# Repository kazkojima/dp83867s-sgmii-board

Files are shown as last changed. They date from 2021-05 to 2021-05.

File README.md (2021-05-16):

# KiCAD files of a SGMII PHY board with TI DP83867S

KiCAD files of a simple SGMII PHY

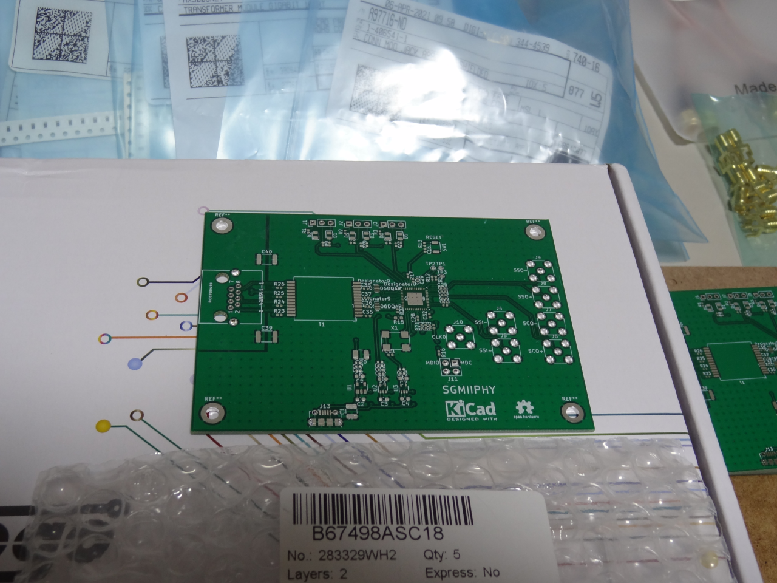
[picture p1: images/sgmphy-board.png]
print board


It works with an ECP5 evaluation board LFE5UM5G-85F-EVN running [LiteX](https://github.com/enjoy-digital/litex).

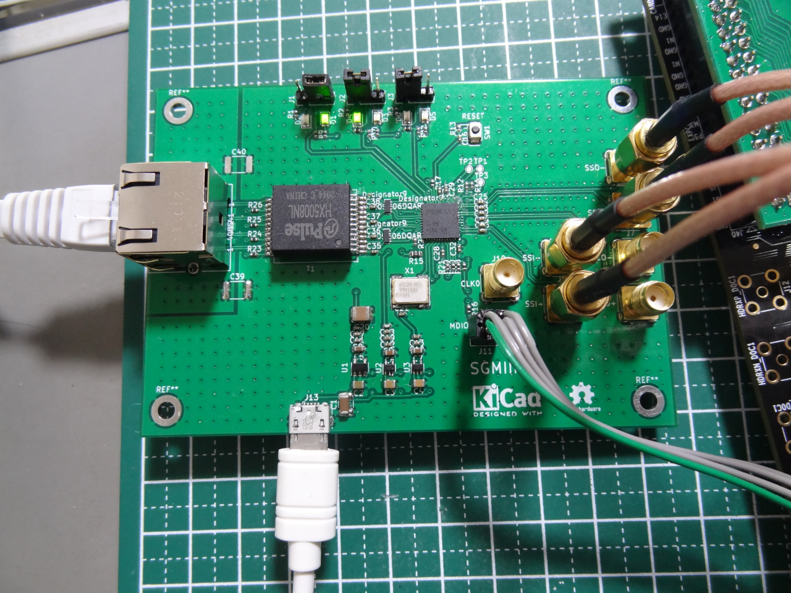
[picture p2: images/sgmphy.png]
With LEF5UM5G-85G


## Problems

* 1.0V LDO will be too hot when supplying 5V. It should be bigger package which has lower junction thermal resistance. 3.3V supply will be OK.

* SMA connectors were a bit too close to each other.

* REFCLK LDVS and CLKOUT outputs could be optional because almost MACs has their own CDR.

* Datasheet says "at minimum a 4-layer PCB should be used. However a 6-layer board is recommended." This 2-layer PCB violates it :-)

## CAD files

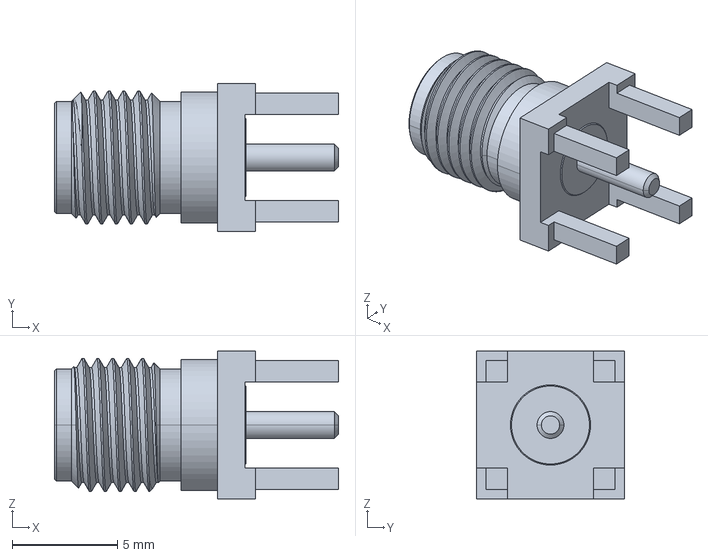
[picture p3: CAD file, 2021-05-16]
anphenole-132134.stp
13.5 x 7.00 x 7.00 mm

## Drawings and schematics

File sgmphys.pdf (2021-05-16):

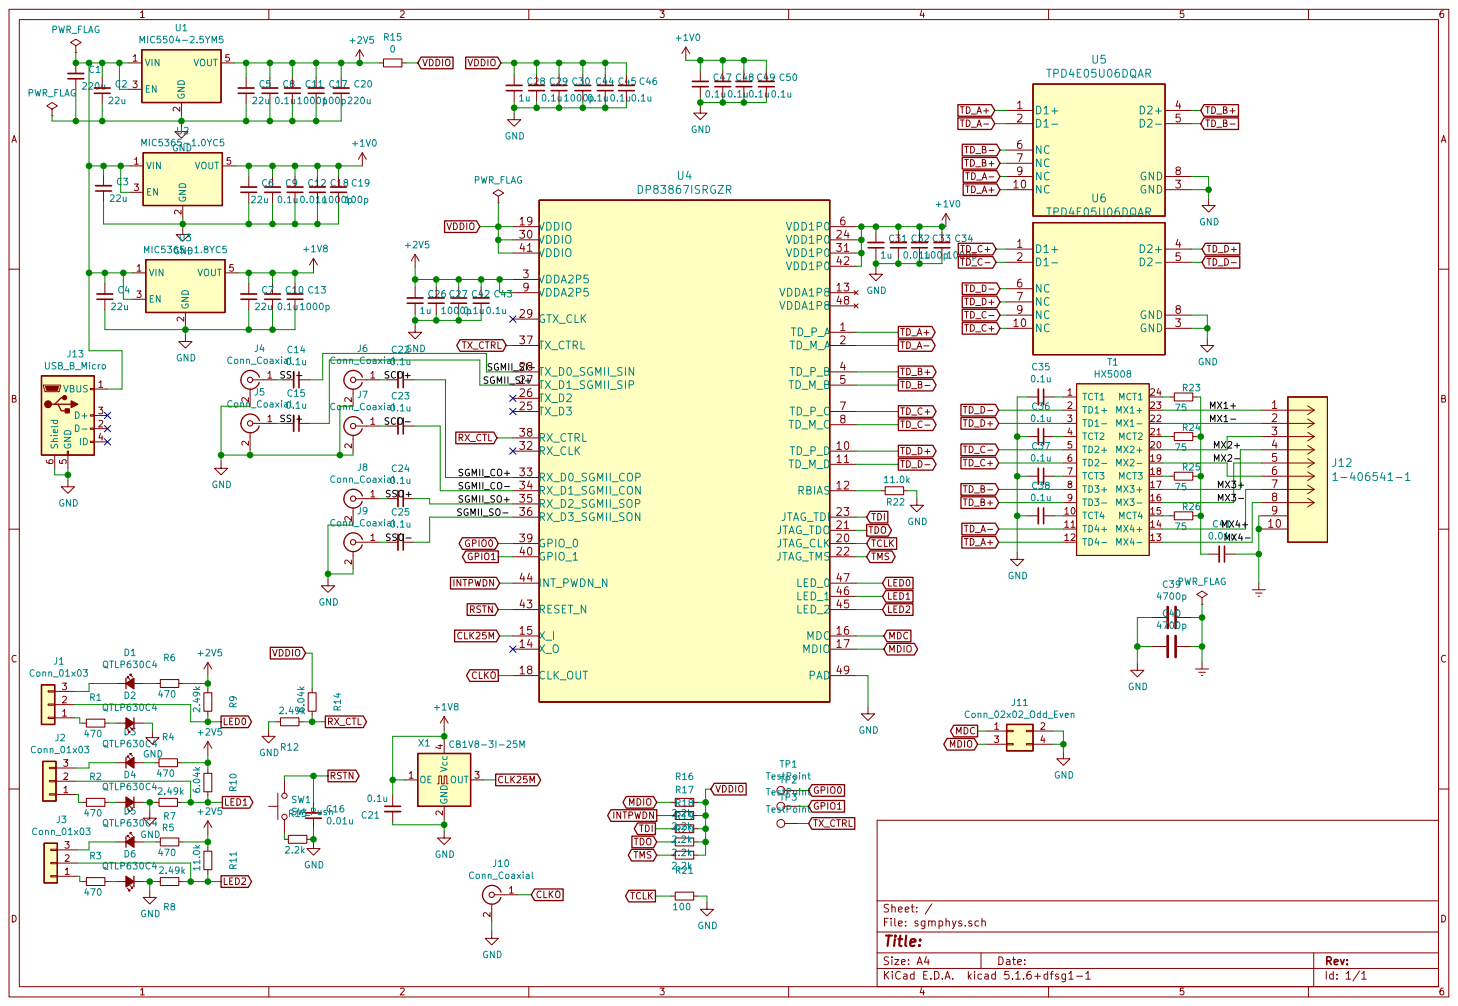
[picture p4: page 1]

File: sgmphys.sch Sheet: /
Id: 1/1 Title:

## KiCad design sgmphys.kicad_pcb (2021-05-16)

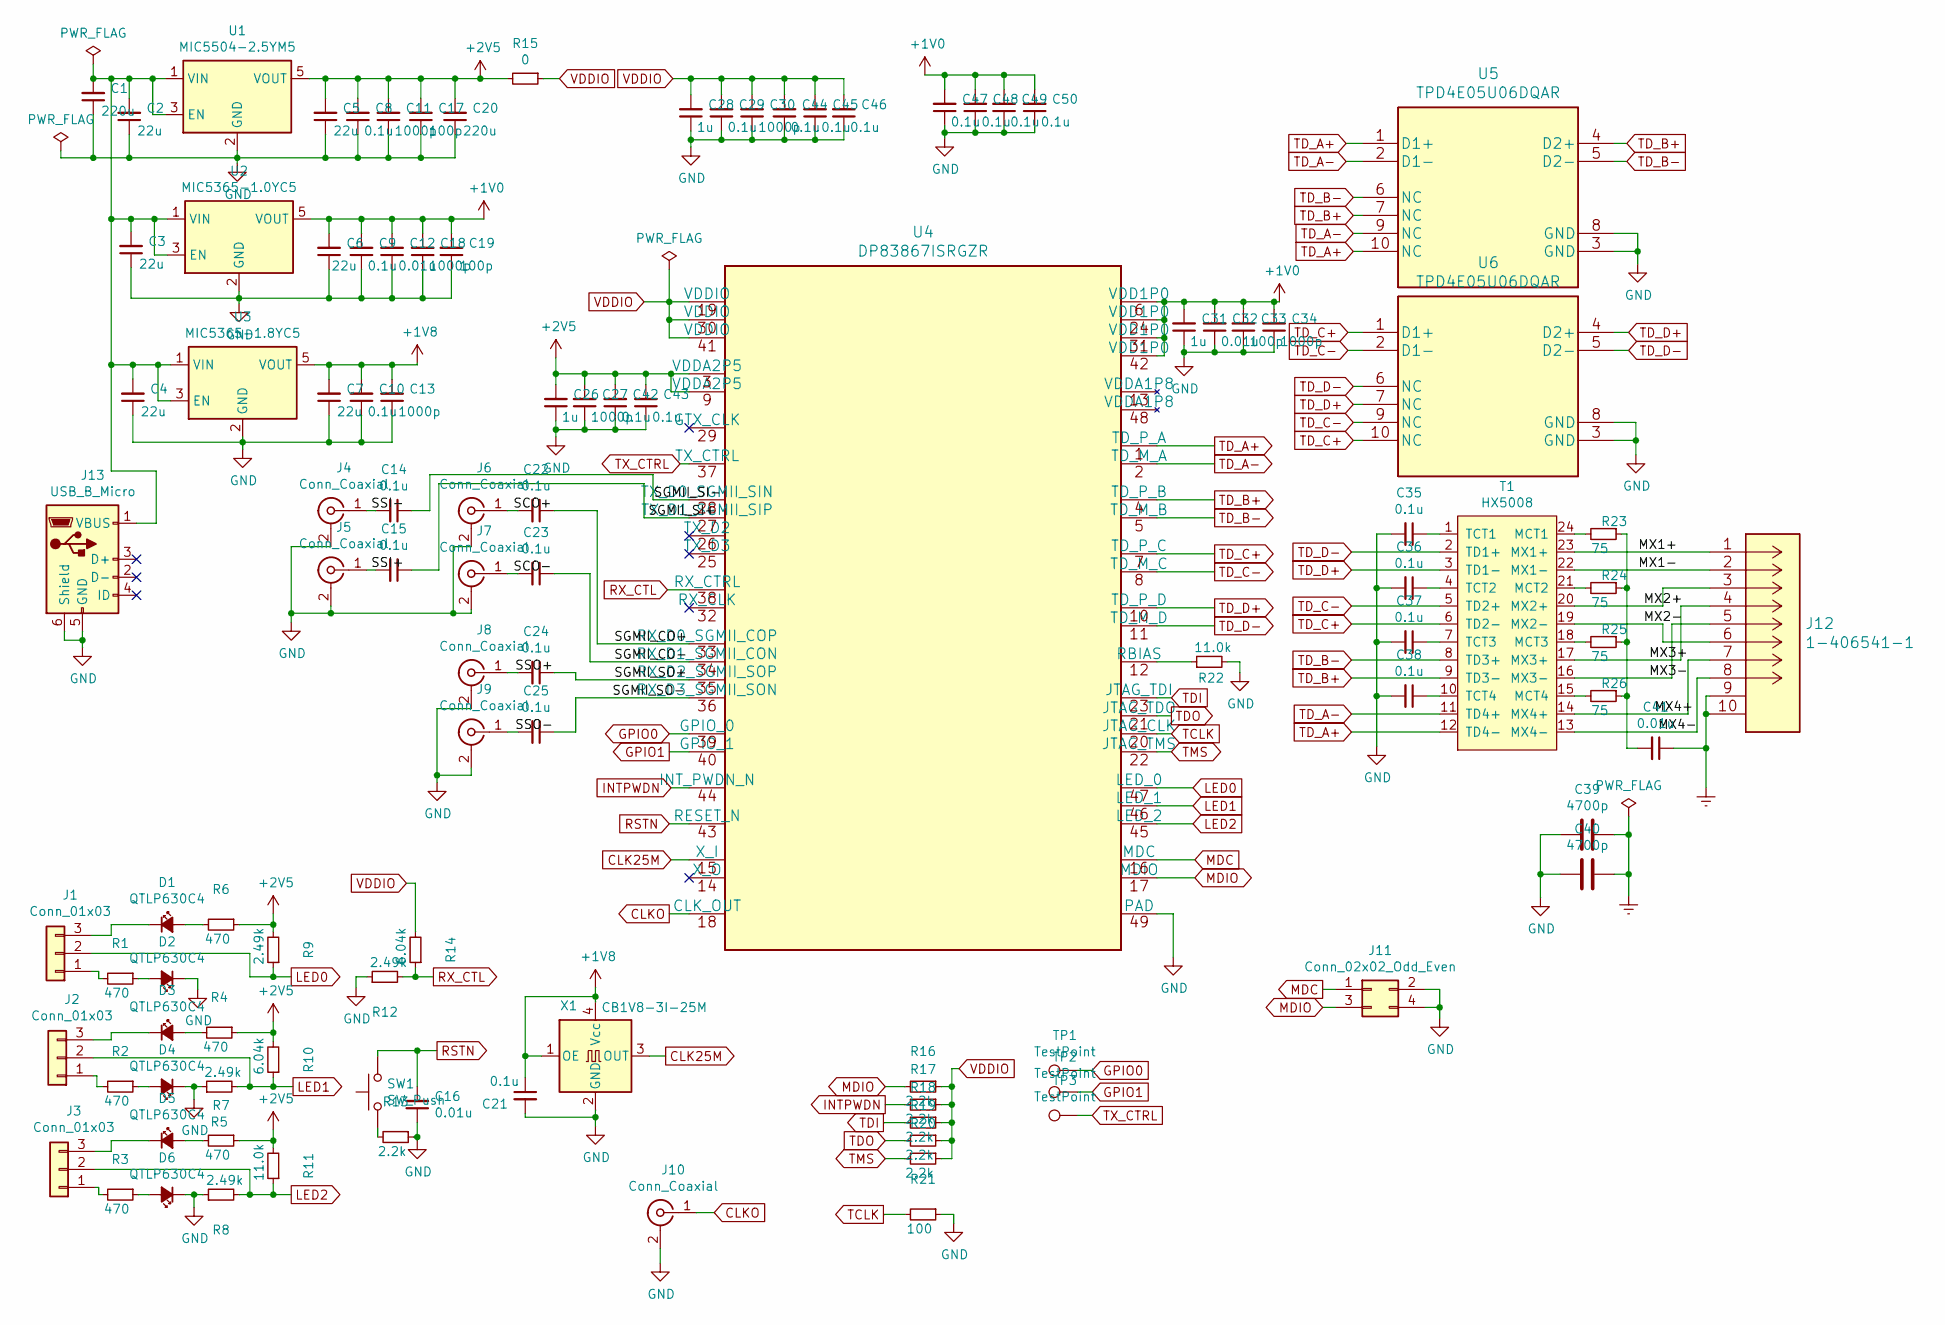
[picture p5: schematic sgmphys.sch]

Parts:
C1, C20: 220u; C_1210_3225Metric
C2, C3, C4, C5, C6, C7: 22u; C_0603_1608Metric
C8, C9, C10, C14, C15, C21, C22, C23, C24, C25, C29, C35, C36, C37, C38, C42, C43, C44, C45, C46, C47, C48, C49, C50: 0.1u; C_0402_1005Metric
C11, C13, C18, C27, C30, C34: 1000p; C_0402_1005Metric
C12, C16, C32, C41: 0.01u; C_0402_1005Metric
C17, C19, C33: 100p; C_0402_1005Metric
C26, C28, C31: 1u; C_0402_1005Metric
C39, C40: 4700p; C_1812_4532Metric
D1, D2, D3, D4, D5, D6: QTLP630C4; D_0805_2012Metric
J1, J2, J3: Conn_01x03; PinHeader_1x03_P2.54mm_Vertical
J4, J5, J6, J7, J8, J9, J10: Conn_Coaxial; SMA_Amphenol_132134_Vertical
J11: Conn_02x02_Odd_Even; PinHeader_2x02_P2.54mm_Vertical
J12: 1-406541-1
J13: USB_B_Micro; USB_Micro-B_Molex-105017-0001
R1, R2, R3, R4, R6, R7: 470; R_0402_1005Metric
R5, R8, R9, R12: 2.49k; R_0402_1005Metric
R10, R14: 6.04k; R_0402_1005Metric
R11, R22: 11.0k; R_0402_1005Metric
R13, R16, R17, R18, R19, R20: 2.2k; R_0402_1005Metric
R15: 0; R_0603_1608Metric
R21: 100; R_0402_1005Metric
R23, R24, R25, R26: 75; R_0402_1005Metric
SW1: SW_Push; SW_SPST_B3U-1000P
T1: HX5008; HX5008NL
TP1, TP2, TP3: TestPoint; TestPoint_Pad_D1.0mm
U1: MIC5504-2.5YM5; SOT-23-5
U2: MIC5365-1.0YC5; SOT-353_SC-70-5
U3: MIC5365-1.8YC5; SOT-353_SC-70-5
U4: DP83867ISRGZR
U5, U6: TPD4E05U06DQAR
X1: CB1V8-3I-25M; Oscillator_SMD_SeikoEpson_SG8002CA-4Pin_7.0x5.0mm

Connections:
+1V0: C6.2, C9.2, C12.2, C18.2, C19.2, C31.2, C32.2, C33.2, C34.2, C47.2, C48.2, C49.2, C50.2, U2.5 (VOUT), U4.6 (VDD1P0), U4.24 (VDD1P0), U4.31 (VDD1P0), U4.42 (VDD1P0)
+1V8: C7.2, C10.2, C13.2, C21.1, U3.5 (VOUT), X1.1 (OE), X1.4 (Vcc)
+2V5: C5.2, C8.2, C11.2, C17.2, C20.2, C26.2, C27.2, C42.2, C43.2, R4.1, R6.1, R7.1, R9.2, R10.2, R11.2, R15.2, U1.5 (VOUT), U4.3 (VDDA2P5), U4.9 (VDDA2P5)
/MX1+: J12.1, T1.23 (MX1+)
/MX1-: J12.2, T1.22 (MX1-)
/MX2+: J12.3, T1.20 (MX2+)
/MX2-: J12.6, T1.19 (MX2-)
/MX3+: J12.4, T1.17 (MX3+)
/MX3-: J12.5, T1.16 (MX3-)
/MX4+: J12.7, T1.14 (MX4+)
/MX4-: J12.8, T1.13 (MX4-)
/SCO+: C22.2, J6.1 (In)
/SCO-: C23.2, J7.1 (In)
/SGMII_CO+: C22.1, U4.33 (RX_D0_SGMII_COP)
/SGMII_CO-: C23.1, U4.34 (RX_D1_SGMII_CON)
/SGMII_SI+: C15.1, U4.27 (TX_D1_SGMII_SIP)
/SGMII_SI-: C14.1, U4.28 (TX_D0_SGMII_SIN)
/SGMII_SO+: C24.1, U4.35 (RX_D2_SGMII_SOP)
/SGMII_SO-: C25.1, U4.36 (RX_D3_SGMII_SON)
/SSI+: C15.2, J5.1 (In)
/SSI-: C14.2, J4.1 (In)
/SSO+: C24.2, J8.1 (In)
/SSO-: C25.2, J9.1 (In)
CLK25M: U4.15 (X_I), X1.3 (OUT)
CLKO: J10.1 (In), U4.18 (CLK_OUT)
Earth: C39.1, C40.1, C41.1, J12.9 (SHIELD), J12.10 (SHIELD)
GND: C1.1, C2.1, C3.1, C4.1, C5.1, C6.1, C7.1, C8.1, C9.1, C10.1, C11.1, C12.1, C13.1, C16.1, C17.1, C18.1, C19.1, C20.1, C21.2, C26.1, C27.1, C28.1, C29.1, C30.1, C31.1, C32.1, C33.1, C34.1, C35.2, C36.2, C37.2, C38.2, C39.2, C40.2, C42.1, C43.1, C44.1, C45.1, C46.1, C47.1, C48.1, C49.1, C50.1, D2.1 (K), D4.1 (K), D6.1 (K), J4.2 (Ext), J5.2 (Ext), J6.2 (Ext), J7.2 (Ext), J8.2 (Ext), J9.2 (Ext), J10.2 (Ext), J11.2, J11.4, J13.5 (GND), J13.6 (Shield), R5.1, R8.1, R12.1, R13.1, R21.1, R22.2, U1.2 (GND), U2.2 (GND), U3.2 (GND), U4.49 (PAD), U4.V, U5.3 (GND), U5.8 (GND), U6.3 (GND), U6.8 (GND), X1.2 (GND)
GPIO0: TP1.1, U4.39 (GPIO_0)
GPIO1: TP2.1, U4.40 (GPIO_1)
INTPWDN: R17.2, U4.44 (INT_PWDN_N)
LED0: J1.2, R9.1, U4.47 (LED_0)
LED1: J2.2, R5.2, R10.1, U4.46 (LED_1)
LED2: J3.2, R8.2, R11.1, U4.45 (LED_2)
MDC: J11.1, U4.16 (MDC)
MDIO: J11.3, R16.2, U4.17 (MDIO)
unnamed: C1.2, C2.2, C3.2, C4.2, J13.1 (VBUS), U1.1 (VIN), U1.3 (EN), U2.1 (VIN), U2.3 (EN), U3.1 (VIN), U3.3 (EN)
unnamed: C35.1, T1.1 (TCT1)
unnamed: C36.1, T1.4 (TCT2)
unnamed: C37.1, T1.7 (TCT3)
unnamed: C38.1, T1.10 (TCT4)
unnamed: C41.2, R23.1, R24.1, R25.1, R26.1
unnamed: D1.1 (K), J1.3
unnamed: D1.2 (A), R6.2
unnamed: D2.2 (A), R1.1
unnamed: D3.1 (K), J2.3
unnamed: D3.2 (A), R4.2
unnamed: D4.2 (A), R2.1
unnamed: D5.1 (K), J3.3
unnamed: D5.2 (A), R7.2
unnamed: D6.2 (A), R3.1
unnamed: J1.1, R1.2
unnamed: J2.1, R2.2
unnamed: J3.1, R3.2
unnamed: R13.2, SW1.1
unnamed: R22.1, U4.12 (RBIAS)
unnamed: R23.2, T1.24 (MCT1)
unnamed: R24.2, T1.21 (MCT2)
unnamed: R25.2, T1.18 (MCT3)
unnamed: R26.2, T1.15 (MCT4)
RSTN: C16.2, SW1.2, U4.43 (RESET_N)
RX_CTL: R12.2, R14.1, U4.38 (RX_CTRL)
TCLK: R21.2, U4.20 (JTAG_CLK)
TDI: R18.2, U4.23 (JTAG_TDI)
TDO: R19.2, U4.21 (JTAG_TDO)
TD_A+: T1.12 (TD4-), U4.1 (TD_P_A), U5.1 (D1+), U5.10 (NC)
TD_A-: T1.11 (TD4+), U4.2 (TD_M_A), U5.2 (D1-), U5.9 (NC)
TD_B+: T1.9 (TD3-), U4.4 (TD_P_B), U5.4 (D2+), U5.7 (NC)
TD_B-: T1.8 (TD3+), U4.5 (TD_M_B), U5.5 (D2-), U5.6 (NC)
TD_C+: T1.6 (TD2-), U4.7 (TD_P_C), U6.1 (D1+), U6.10 (NC)
TD_C-: T1.5 (TD2+), U4.8 (TD_M_C), U6.2 (D1-), U6.9 (NC)
TD_D+: T1.3 (TD1-), U4.10 (TD_P_D), U6.4 (D2+), U6.7 (NC)
TD_D-: T1.2 (TD1+), U4.11 (TD_M_D), U6.5 (D2-), U6.6 (NC)
TMS: R20.2, U4.22 (JTAG_TMS)
TX_CTRL: TP3.1, U4.37 (TX_CTRL)
VDDIO: C28.2, C29.2, C30.2, C44.2, C45.2, C46.2, R14.2, R15.1, R16.1, R17.1, R18.1, R19.1, R20.1, U4.19 (VDDIO), U4.30 (VDDIO), U4.41 (VDDIO)

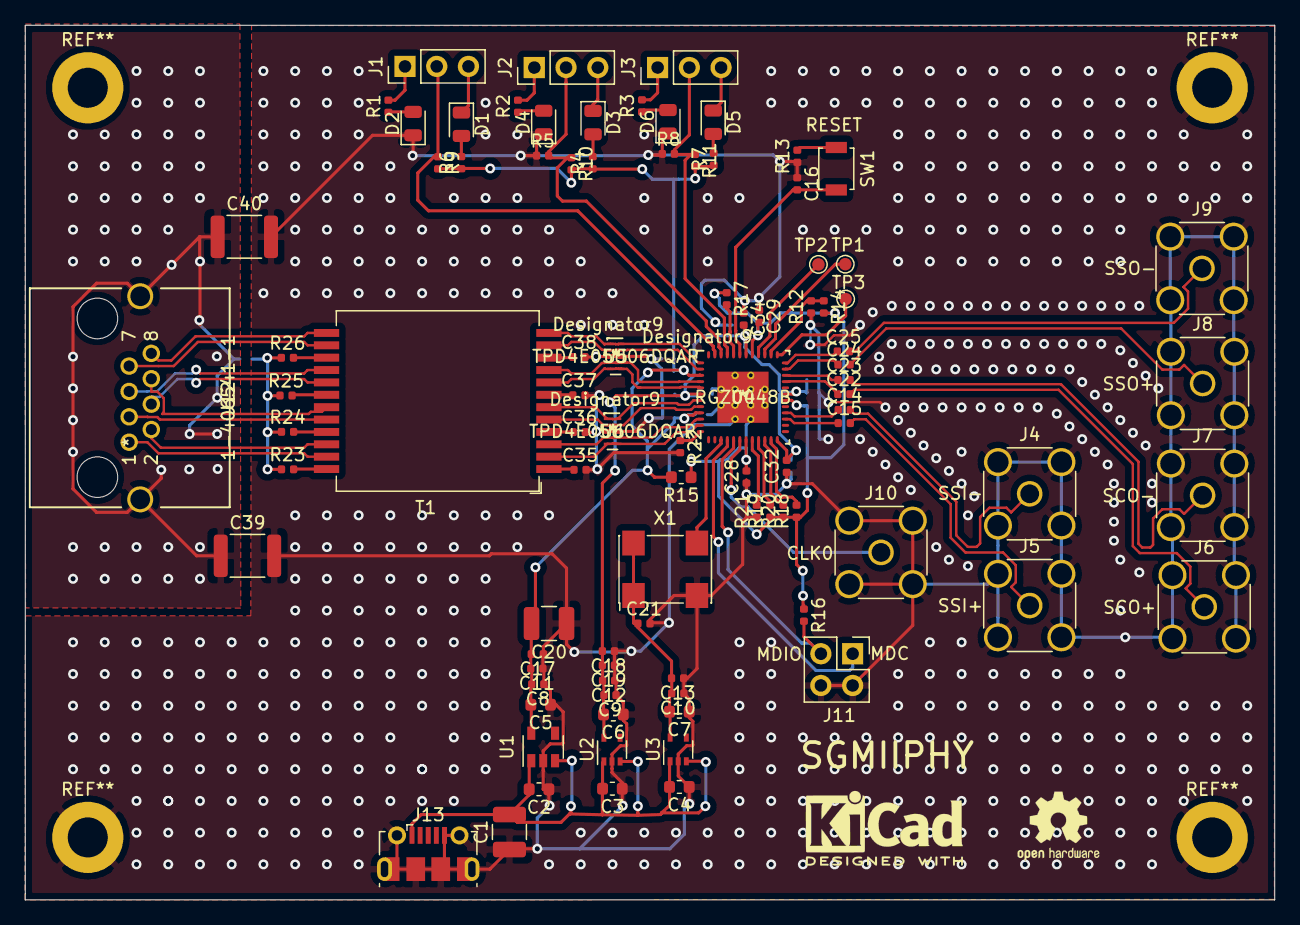
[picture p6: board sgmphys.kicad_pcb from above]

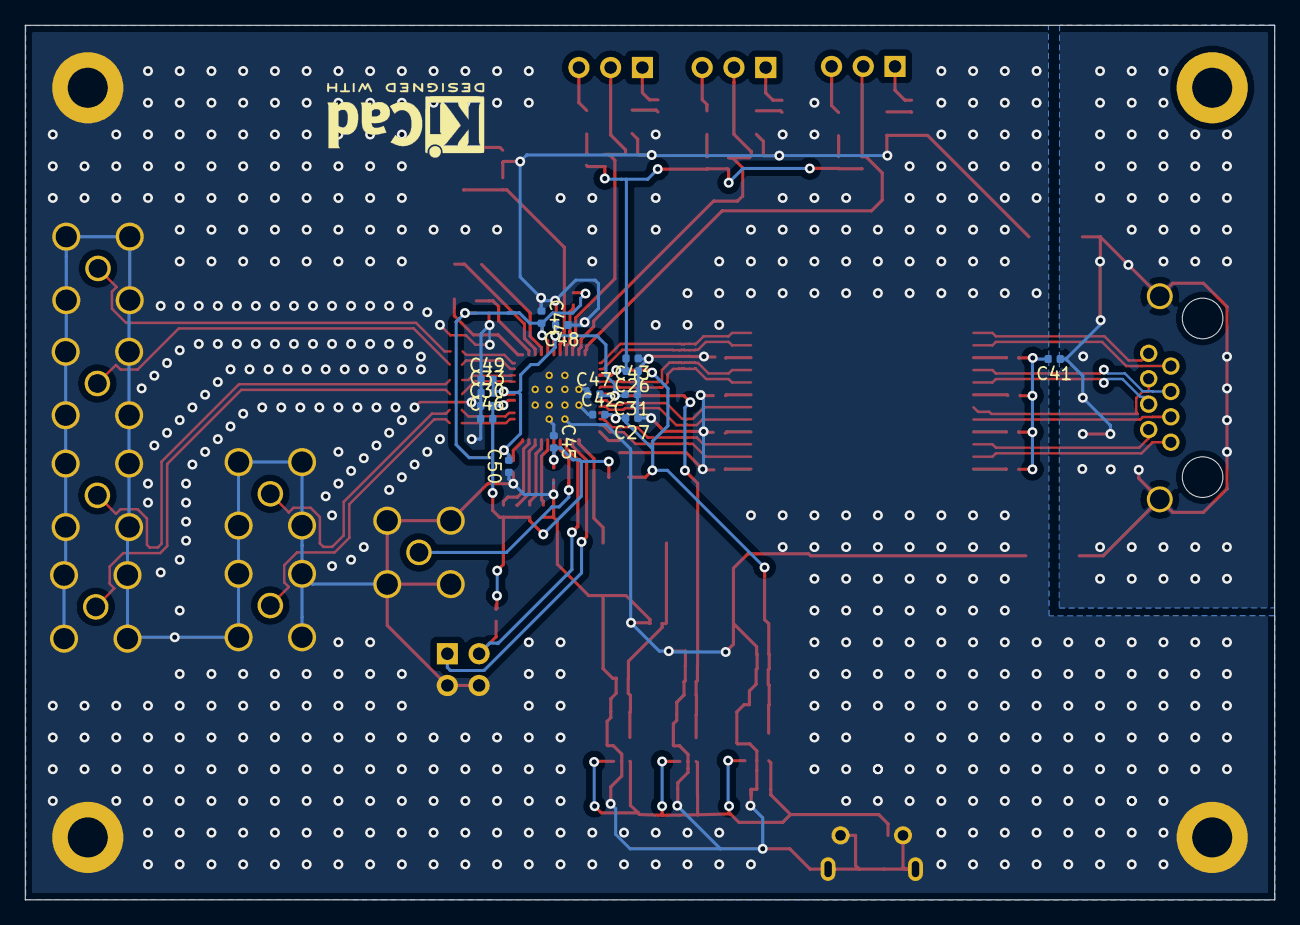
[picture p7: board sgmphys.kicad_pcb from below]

Board: 2 copper layers, 100.0 x 70.0 mm, 107 parts (15 on the bottom side), 75 nets.

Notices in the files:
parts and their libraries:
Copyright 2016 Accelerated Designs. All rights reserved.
